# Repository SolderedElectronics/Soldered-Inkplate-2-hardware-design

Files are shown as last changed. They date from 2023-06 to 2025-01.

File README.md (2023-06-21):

# Inkplate 2 Hardware design

## About the product

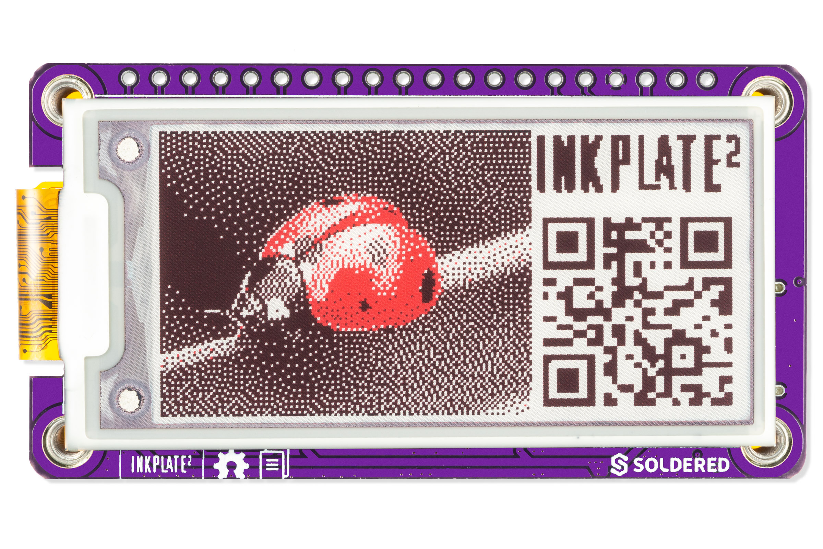
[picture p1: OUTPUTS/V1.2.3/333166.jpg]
Inkplate 2
|  |
| :----------------------------------------------------------: |
|      [Buy Inkplate 2](https://www.solde.red/333166)      |

The Inkplate 2 is an Arduino-compatible board that features a 2.13" three-color e-paper display. It is a plug-and-play device, programmable via USB port, and controlled by an ESP32 microcontroller. Moreover, it connects to the internet via WiFi or Bluetooth. Since it uses only 8uA in low-power mode, it can last for months on a single Li-ion battery charge. It's simple enough to be used by beginners, but it also offers plenty of features and a user-friendly platform for advanced users. Inkplate 2 has it all, packed on a small-factor board.

If you're like us, when you first saw an e-book reader, you thought "If only I could use a screen like this in my project". Thanks to the exceptional sharpness and contrast, the ability to display in sunlight and truly unprecedented efficiency in terms of energy (it consumes energy only when changing the content on the screen), electronic paper is the ideal choice for many applications. Inkplate 2, continuing the tradition of the now well-known Inkplate series, offers a variation of e-paper accessible to hobbyists and everyone else in a way that we have created a plug-and-play hardware that is really easy to use, and is compatible with Arduino and micropython.

## Repository contents

All Soldered Electronics hardware designed in KiCAD, and repositories are organized in the following way:

- CAD folder - contains KiCAD files (Schematics, Board, Panel Board), sorted by version. Change log lists all changes between versions.
- OUTPUTS - contains useful files, such as Bill of Materials (BOM), PDF of schematics, 3D .step file of the board and gerber files, sorted by version. 
- OUTPUTS -> Compliance - Certificates and useful legal stuff. 

## Want to contribute?

Please feel free to submit a pull request if you have any contributions. We encourage you to submit an issue or pull request if you find a bug. 

## About Soldered

soldered-logo

At Soldered, we design and manufacture a wide selection of electronic products to help you turn your ideas into acts and bring you one step closer to your final project. Our products are intented for makers and crafted in-house by our experienced team in Osijek, Croatia. We believe that sharing is a crucial element for improvement and innovation, and we work hard to stay connected with all our makers regardless of their skill or experience level. Therefore, all our products are open-source. Finally, we always have your back. If you face any problem concerning either your shopping experience or your electronics project, our team will help you deal with it, offering efficient customer service and cost-free technical support anytime. Some of those might be useful for you:

- [Web Store](https://www.soldered.com/shop)
- [Tutorials & Projects](https://soldered.com/learn)
- [Community & Technical support](https://soldered.com/community)

## License info

All Soldered open-source hardware (OSH) is under The TAPR Open Hardware License. Read more in the LICENSE file. 

No warranty - all designs in this repository are distributed in the hope that they will be useful, but without any warranty. They are provided "AS IS", therefore without warranty of any kind, either expressed or implied. The entire quality and performance of what you do with the contents of this repository are your responsibility. In no event, Soldered Electronics will be liable for your damages, losses, including any general, special, incidental or consequential damage arising out of the use or inability to use the contents of this repository. 

## Have fun! 
And thank you from your fellow makers at Soldered Electronics.

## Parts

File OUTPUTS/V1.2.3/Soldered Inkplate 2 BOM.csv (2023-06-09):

Id | Designator | Package | Quantity | Designation | Supplier and ref
1 | K15,K13,K16,K22,K4,K12,K9,K3,K8,K14,K21,K18,K10,K25,K6,K17,K1,K7,K5,K11 | HEADER_MALE_1X1_Inkplate | 20 | HEADER_MALE_1X1_Inkplate
2 | D1 | 0402LED | 1 | RED
3 | PAD3,PAD5,PAD2,PAD1,PAD4 | PAD_2x1.5 | 5 | PAD_2x1.5
4 | Q2,Q3 | SOT-23-3 | 2 | NPN
5 | H3,H4,H2,H1 | Standoff_M3 | 4 | Standoff_M3
6 | C10,C6,C26,C5,C3,C12 | 0603C | 6 | 100n
7 | R2,R12,R1,R13 | 0603R | 4 | 10k
8 | U3 | SOT-23-5 | 1 | MCP73831T-2ATI/OT
9 | R15,R3,R16,R17,R18,R19,R14,R11 | 0603R | 8 | 100k
10 | R8,R9 | 0603R | 2 | 1k
11 | C4,C9,C7,C2,C13 | 0603C | 5 | 2u2
12 | C22,C23 | 1206C | 2 | CL31B475KBHNFNE
13 | D5,D4,D6 | SOD−123 | 3 | MBR0530T1G
14 | R4 | 0603R | 1 | 47R
15 | C11,C1,C8 | 1206C | 3 | 10u
16 | Q1 | SOT-23-3 | 1 | SSM3J358R,LF
17 | K20 | U262-161N-4BVC11 | 1 | U262-161N-4BVC11
18 | R22 | 0603R | 1 | 0603WAF470LT5E
19 | D2 | SOD-323 | 1 | BAT20J
20 | C19,C15,C18,C24,C14,C20,C21,C17,C16 | 0603C | 9 | C1608X5R1H105K080AB
21 | L1 | Inductor_SMD_7x6.6 | 1 | PSPMAA0603-100M-ANF
22 | U4 | TPS7A2633DRVR | 1 | TPS7A2633DRVR
23 | F1 | 1206FUSE | 1 | 1206FUSE_500mA
24 | R5 | 0402R | 1 | 2k2
25 | K19 | TX2400-FPC-5015 | 1 | TX2400-FPC-5015
26 | R6,R7 | 0603R | 2 | 5k1
27 | U6 | SOT-23-5 | 1 | TPS3840PL27DBVR
28 | K24 | SFV24R-2STBE1HLF | 1 | SFV24R-1STBE1HLF
29 | U1 | ESP32-WROVER | 1 | ESP32-WROVER-IE-N4R8
30 | SW1 | YTSA007A0151803B | 1 | YTSA007A0151803B
31 | R10 | 0603R | 1 | 2k49
32 | U2 | SOP-16 | 1 | CH340C
33 | Q7 | SOT-23-3 | 1 | CJ2310
34 | K2 | easyC-connector | 1 | easyC-SMD
35 | R21 | 0603R | 1 | 1M
36 | U5 | GDEH0213Z19 | 1 | GDEH0213Z19

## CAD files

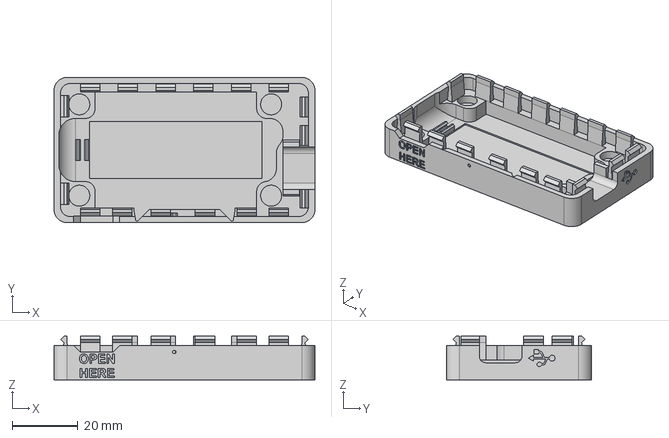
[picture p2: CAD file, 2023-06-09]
CAD/V1.2.3/Source 3D files/Soldered Inkplate 2 Bottom STEP.step
79.5 x 44.2 x 13.3 mm

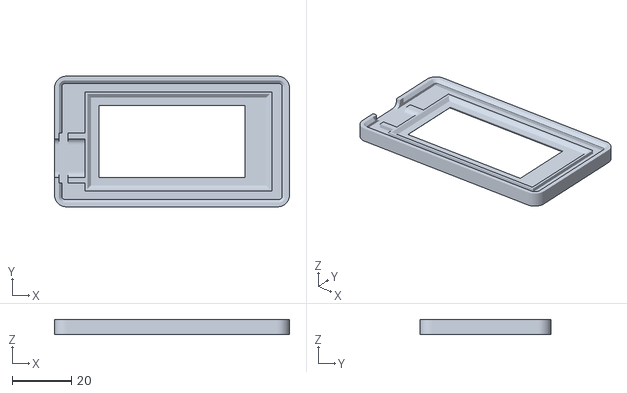
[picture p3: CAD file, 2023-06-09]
OUTPUTS/V1.2.3/3D printable files/Soldered Inkplate 2 Top STL.stl
79.5 x 44.2 x 5.00

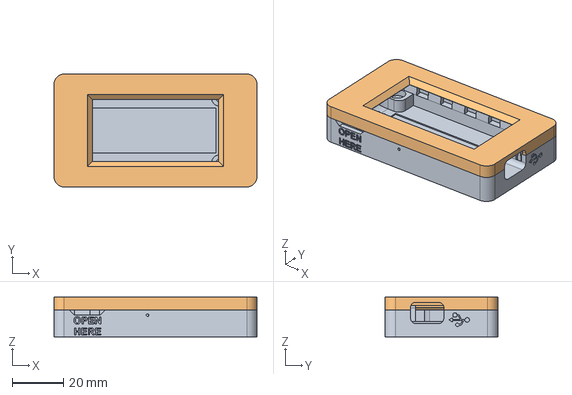
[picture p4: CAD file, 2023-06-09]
CAD/V1.2.3/Source 3D files/Soldered Inkplate 2 Case STEP.step
79.5 x 44.2 x 15.5 mm
Inkplate 2 Bottom
Inkplate 2 Top

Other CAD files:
OUTPUTS/V1.2.3/3D printable files/Soldered Inkplate 2 Case STL.stl
CAD/V1.2.3/Source 3D files/Soldered Inkplate 2 Top STEP.step
OUTPUTS/V1.2.3/3D printable files/Soldered Inkplate 2 Bottom STL.stl
CAD/V1.2.3/Source 3D files/Soldered Inkplate 2 Bottom 3D.f3d
CAD/V1.2.3/Source 3D files/Soldered Inkplate 2 Case 3D.f3z
CAD/V1.2.3/Source 3D files/Soldered Inkplate 2 Top 3D.f3d

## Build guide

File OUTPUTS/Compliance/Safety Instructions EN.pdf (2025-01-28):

PLEASE RETAIN THIS INFORMATION FOR FUTURE REFERENCE.

BEFORE USING THIS PRODUCT, READ ALL INSTRUCTION IN THIS DOCUMENT.

Product name: Soldered Inkplate 2
Getting started: To get started, please visit www.soldered.com

## WARNINGS

- This product should not be covered and should be operated in well ventilated enviroment.
- The product should be placed on a stable, flat, non-conductive surface and should not be contacted by conductive items.
- Connection of other devices may affect compliance or result in damage to the unit, and invalidate the warranty.
- Where peripherals are connected that do not include the cable or connector, the cable or connector used must offer adequate insulation and operation in order that the requirements of the relevant performance and safety requirements are met.
- There is a danger of explosion if the battery is incorrectly placed.
- The product should not be used outside of its specified working range.

## INSTRUCTIONS FOR SAFE USE

To avoid malfunction or damage to your device, please observe the following:
- Do not expose it to water, moisture or place on a conductive surface when turned on. Do not handle the unit with wet hands.
- Do not expose it to heat from any source; the product is designed to be used at normal ambient room temperatures. The product is intended to be used inside.
- Take care when handling to avoid mechanical or electrical damage to any part of the unit. Avoid handling the unit while it's powered. Use ESD protection.
- Use only supplied cable (or the cable of the same or higher quality) with the unit.

## COMPLIANCE INFORMATION

The product complies with the relevant provision of the RoHS Directive for the European Union. In common with all Electrical and Electronic Equipment (EEE), the product should not be disposed household waste.

ELECTROMAGNETIC COMPABILITY AND OPERATION

- The product is in conformity with the protection requirements of EU Council Directive 2014/30/EU on the laws of the Member States relating of electromagnetic compability, and Electromagnetic Compability Regulations 2016 of the UK.
- WARNING: Please do not alter the design of this product, doing so may void your ability to use the product freely, this includes altering the frequency at which product operates.

### Regulatory Compliance and Important Safety Information

Soldered Electronics d.o.o., Vinkovačka cesta 68, 31000 Osijek, Croatia. VAT ID: HR83200237288

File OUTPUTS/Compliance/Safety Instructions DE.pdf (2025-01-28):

BITTE BEWAHREN SIE DIESE INFORMATIONEN ZUR SPÄTEREN VERWENDUNG AUF.
LESEN SIE VOR DER VERWENDUNG DIESES PRODUKTS ALLE ANWEISUNGEN IN DOKUMENT. Produktname: Soldered Inkplate 2
Die ersten Schritte:Besuchen Sie www.soldered.com, um loszulegen.

## WARNUNGEN

- Dieses Produkt sollte nicht abgedeckt werden und in einer gut belüfteten Umgebung betrieben werden.
- Das Produkt sollte auf einer stabilen, flachen, nicht leitenden Oberfläche aufgestellt werden und nicht mit leitenden Gegenständen in Berührung kommen.
- Der Anschluss anderer Geräte kann die Konformität beeinträchtigen oder zu Schäden am Gerät führen und zum Erlöschen der Garantie führen.
- Wenn Peripheriegeräte angeschlossen werden, die nicht das Kabel oder den Stecker enthalten, muss das verwendete Kabel oder muss das verwendete Kabel bzw. der verwendete Steckverbinder eine angemessene Isolierung und Funktion aufweisen, damit die Anforderungen die einschlägigen Leistungs- und Sicherheitsanforderungen erfüllt werden.
- Es besteht Explosionsgefahr, wenn die Batterie falsch eingesetzt wird.
- Das Produkt sollte nicht außerhalb des angegebenen Arbeitsbereichs verwendet werden.

## HINWEISE ZUR SICHEREN ANWENDUNG

Um Fehlfunktionen oder Schäden an Ihrem Gerät zu vermeiden, beachten Sie bitte die folgenden Hinweise:
- Setzen Sie das Gerät nicht Wasser oder Feuchtigkeit aus und stellen Sie es nicht auf eine
leitende Oberfläche, wenn es eingeschaltet ist. Das Gerät nicht mit nassen Händen anfassen.
- Setzen Sie es keiner Wärmequelle aus; das Produkt ist für die Verwendung bei normalen Raumtemperaturen ausgelegt. Das Produkt ist für die Verwendung in Innenräumen vorgesehen.
- Seien Sie bei der Handhabung vorsichtig, um mechanische oder elektrische Schäden an Teilen des Geräts zu vermeiden. Fassen Sie das Gerät nicht an, wenn es unter Spannung steht. Verwenden Sie einen ESD-Schutz.
- Verwenden Sie nur das mitgelieferte Kabel (oder ein gleich- oder höherwertiges Kabel)
mit dem Gerät.

## COMPLIANCE-INFORMATIONEN

Das Produkt entspricht den entsprechenden Bestimmungen der RoHS-Richtlinie für die Europäische Union. Wie alle elektrischen und elektronischen Geräte (EEE), sollte das Produkt nicht über den Hausmüll entsorgt werden.
ELEKTROMAGNETISCHE VERTRÄGLICHKEIT UND BETRIEB
- Das Produkt entspricht den Schutzanforderungen der Richtlinie des EU-Rates 2014/30/EU über die Rechtsvorschriften der Mitgliedstaaten zur elektromagnetischen Verträglichkeit und den Elektromagnetische Verträglichkeitsverordnung 2016 des Vereinigten Königreichs.
- WARNUNG: Bitte verändern Sie nicht das Design dieses Produkts, da dies dazu führen kann, dass Sie das Produkt nicht mehr uneingeschränkt nutzen können.
Dies gilt auch für die Änderung der Frequenz, mit der das Produkt arbeitet.

## Einhaltung gesetzlicher Vorschriften und wichtige

Soldered Electronics d.o.o., Vinkovačka cesta 68, 31000 Osijek, Croatia. VAT ID: HR83200237288

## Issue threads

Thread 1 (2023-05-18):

Can we get a footprint library please

JanZugic, 2023-05-18:
i wish to create a custom case, but for that i need either a 3D model footprint library or a 3D model (preferably STEP) of the unit.

JanZugic, 2023-05-18:
Its in  the outputs folder...

rsoric, 2023-05-19:
Hi @JanZugic

Glad you could find it, let us know if you might need something else for your case design.

-Rob

JanZugic, 2023-05-19:
Hello! Are you located in Zagreb?

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

rsoric, 2023-05-22:
Hi @JanZugic

We are located in Osijek. If you want to get further in touch with us, we recommend the contact form on our website: https://soldered.com/contact/

Closed 2023-05-18.

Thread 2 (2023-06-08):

Can we get the case files in STL format

Jakobu5, 2023-06-08:
Hi,

awesome products you have there guys.

Could you please provide the case files for all of your inkplates also in the STL format?
Thank you!

davidzovko, 2023-06-08:
Hey,

thanks! Of course, we are retrofitting repositories for older Inkplates with the format of this repo, and it will be ready by the end of the next week.

If you need any specific one before, let us know here, and we'll deliver.

Cheers!

Jakobu5, 2023-06-08:
Thanks for the swift reply,
I need the files for the inkplate 2 and inkplate 6 plus
Thanks!

ifadiga, 2023-06-09:
Hello,
[3D printable files_Inkplate2.zip](https://github.com/SolderedElectronics/Soldered-Inkplate-2-hardware-design/files/11702460/3D.printable.files_Inkplate2.zip)
[3D printable files_Inkplate6PLUS.zip](https://github.com/SolderedElectronics/Soldered-Inkplate-2-hardware-design/files/11702461/3D.printable.files_Inkplate6PLUS.zip)

Here are the files for Inkplate 2 and Inkplate 6PLUS.

Closed 2023-06-09.

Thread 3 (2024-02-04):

Neispravna poveznica na sliku u README.md ?

sbravar, 2024-02-04:
https://github.com/SolderedElectronics/Soldered-Inkplate-2-hardware-design/blob/d8ae98a4285a7189eac2a7881446ffaee9f6e620/README.md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

umjesto:

https://github.com/SolderedElectronics/Inkplate-2-hardware-design/blob/main/OUTPUTS/V1.1.1/333166.jpg?raw=true

čini mi se da bi trebalo biti:

https://github.com/SolderedElectronics/Soldered-Inkplate-2-hardware-design/blob/main/OUTPUTS/V1.2.3/333166.jpg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

rsoric, 2024-02-05:
Hello, and thank you for your feedback. We are currently working on automating this process. Soon, all repositories will be updated with the real content. Cheers!

Closed 2024-02-05.

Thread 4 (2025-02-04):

Broken link to https://soldered.com/learn in  inkplate2 README.md

bivanbi, 2025-02-04:
https://github.com/SolderedElectronics/Soldered-Inkplate-2-hardware-design/blob/main/README.md has a link called 'Tutorials & Projects' which points to a non-existing page https://soldered.com/learn
```
bivanbi@eenovo:~$ curl -iksS https://soldered.com/learn 2>&1 | head
HTTP/2 404
```

rsoric, 2025-02-18:
Greetings @bivanbi ,

thanks for pointing it out, this was a leftover link of something not fully implemented yet, but we are working on improving documentation for all our products.

-Rob

Closed 2025-02-18.

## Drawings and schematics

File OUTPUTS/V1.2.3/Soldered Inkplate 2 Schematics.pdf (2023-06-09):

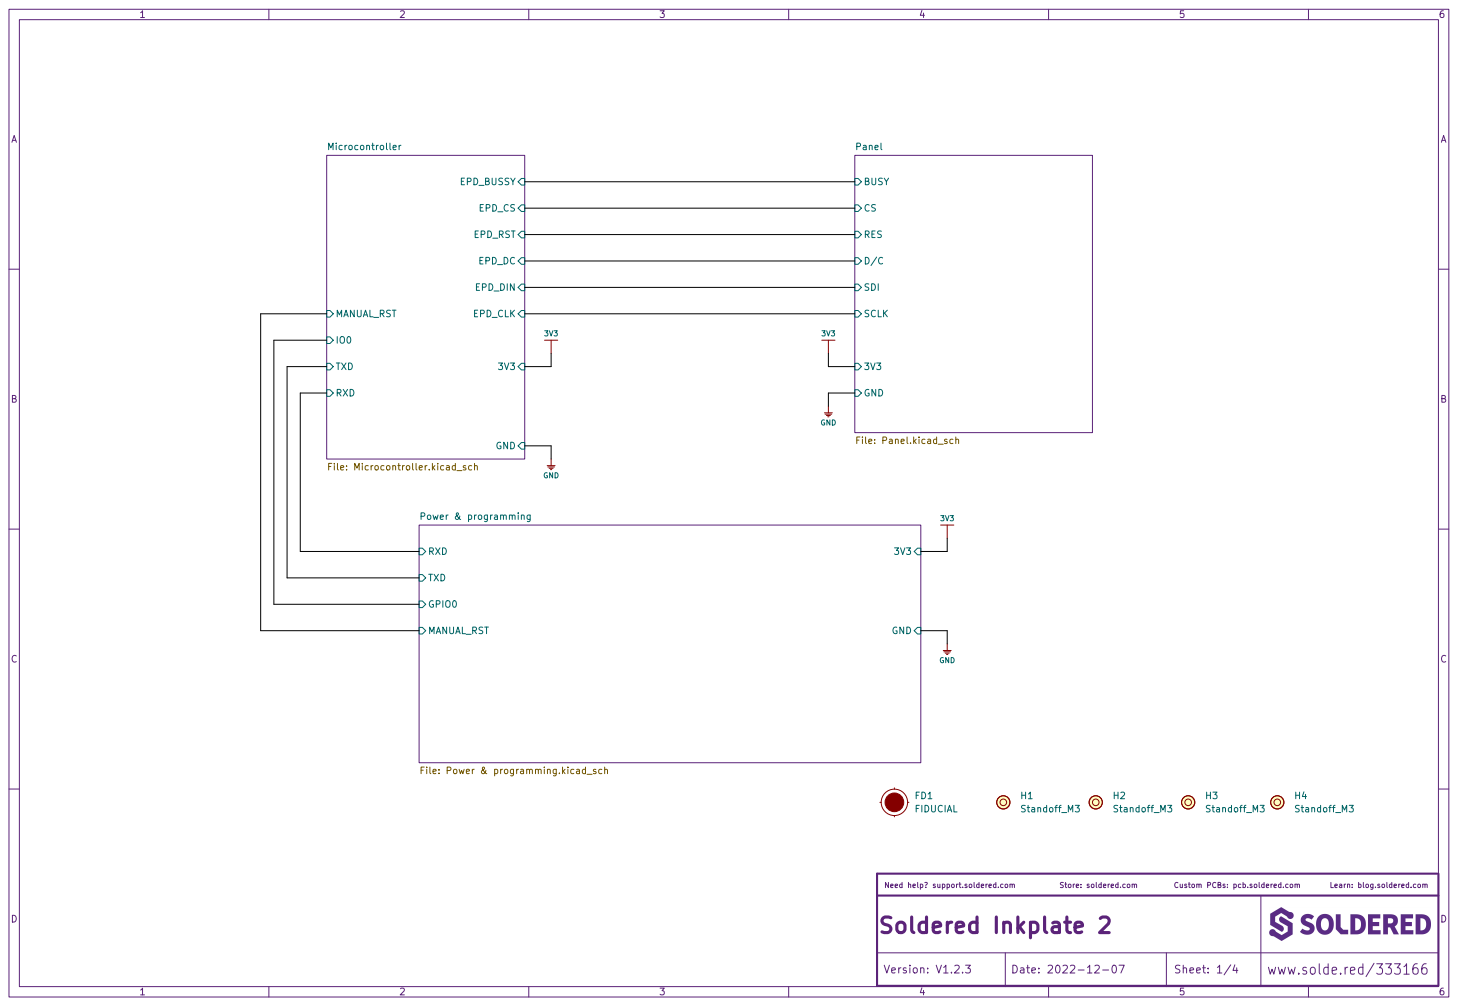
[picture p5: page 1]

Panel File: Panel.kicad_sch RXD

Learn: blog.soldered.com

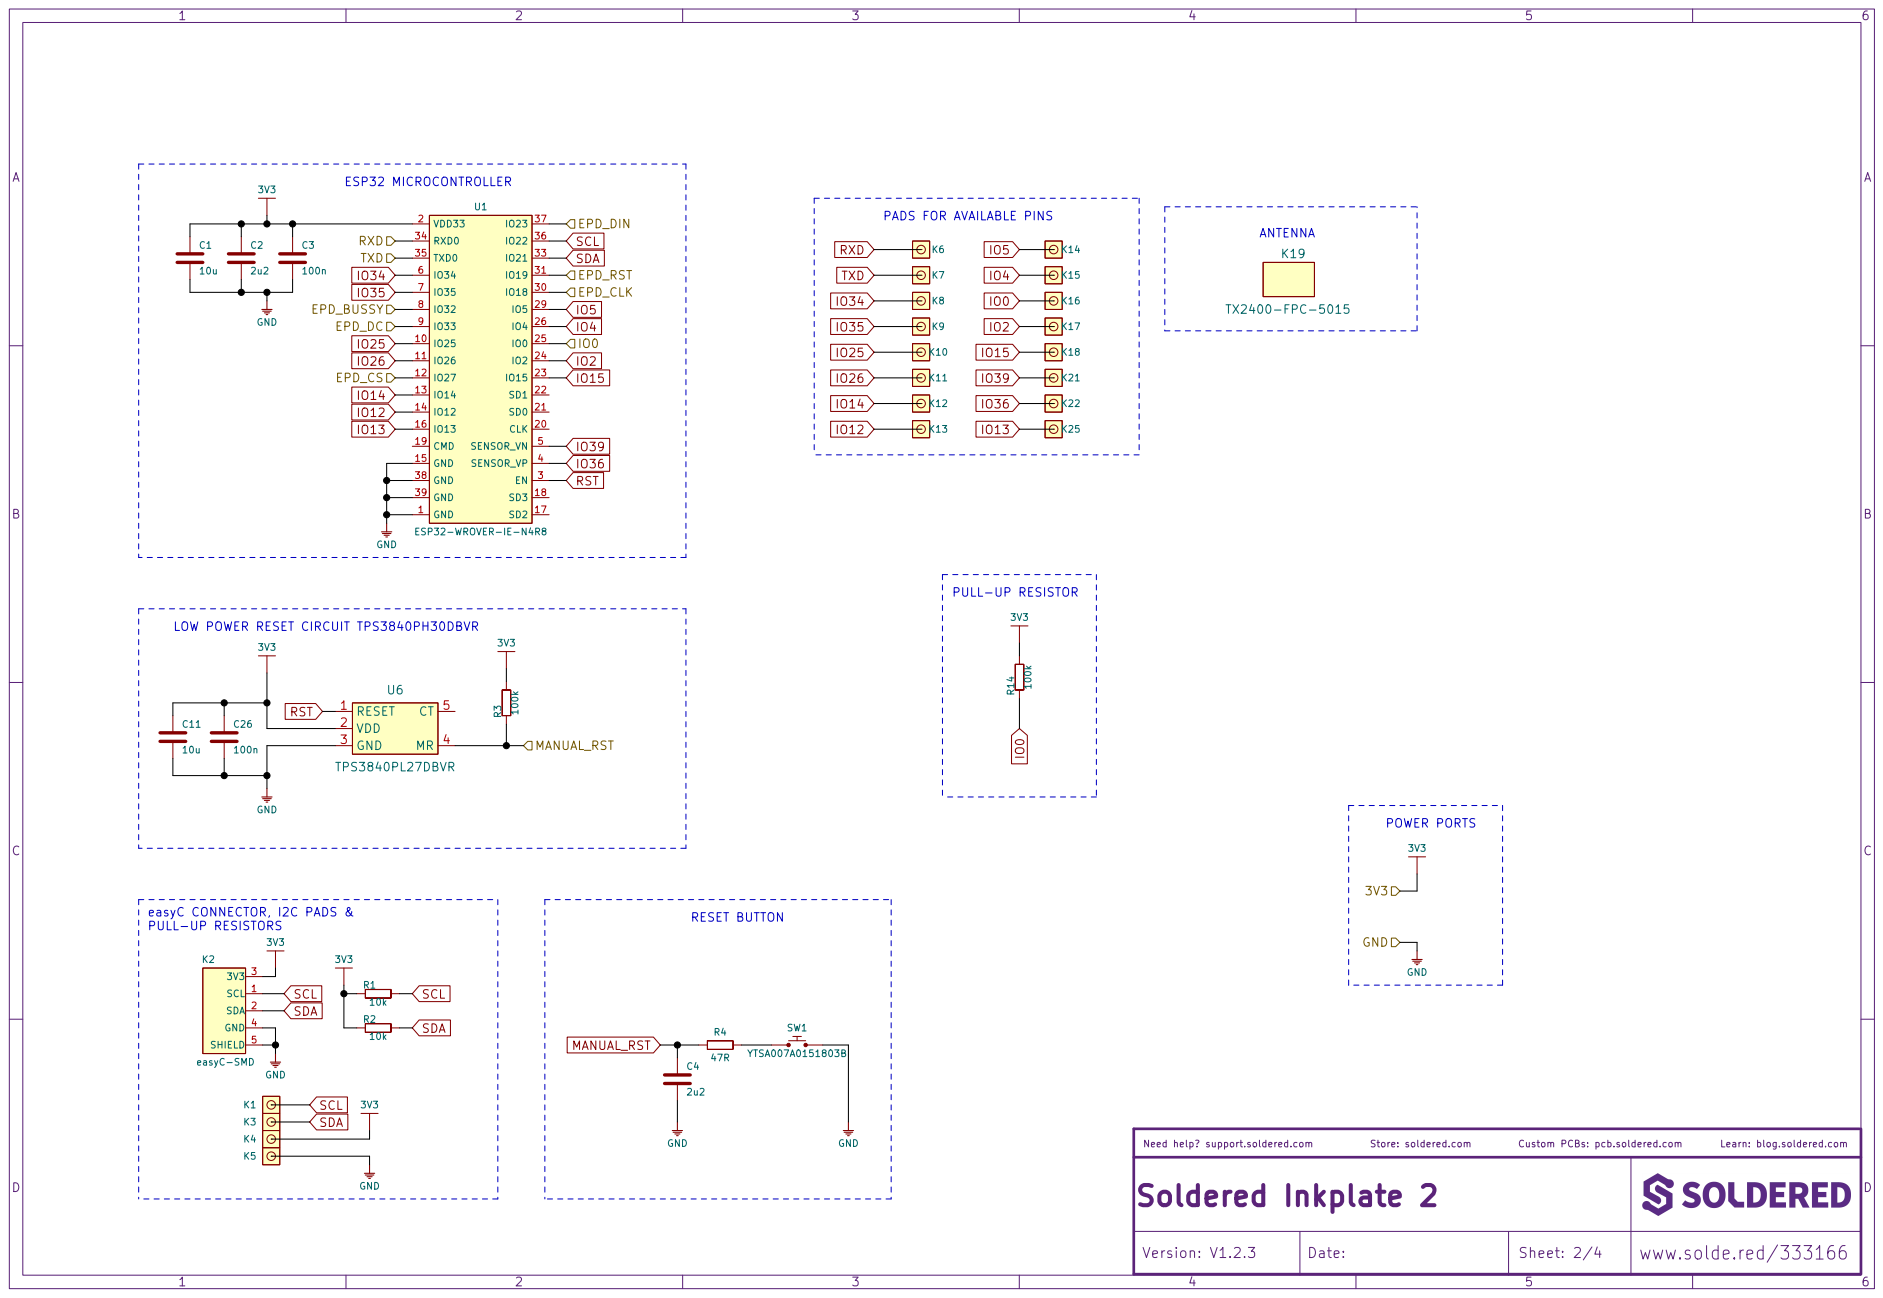
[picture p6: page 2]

LOW POWER RESET CIRCUIT TPS3840PH30DBVR

Learn: blog.soldered.com

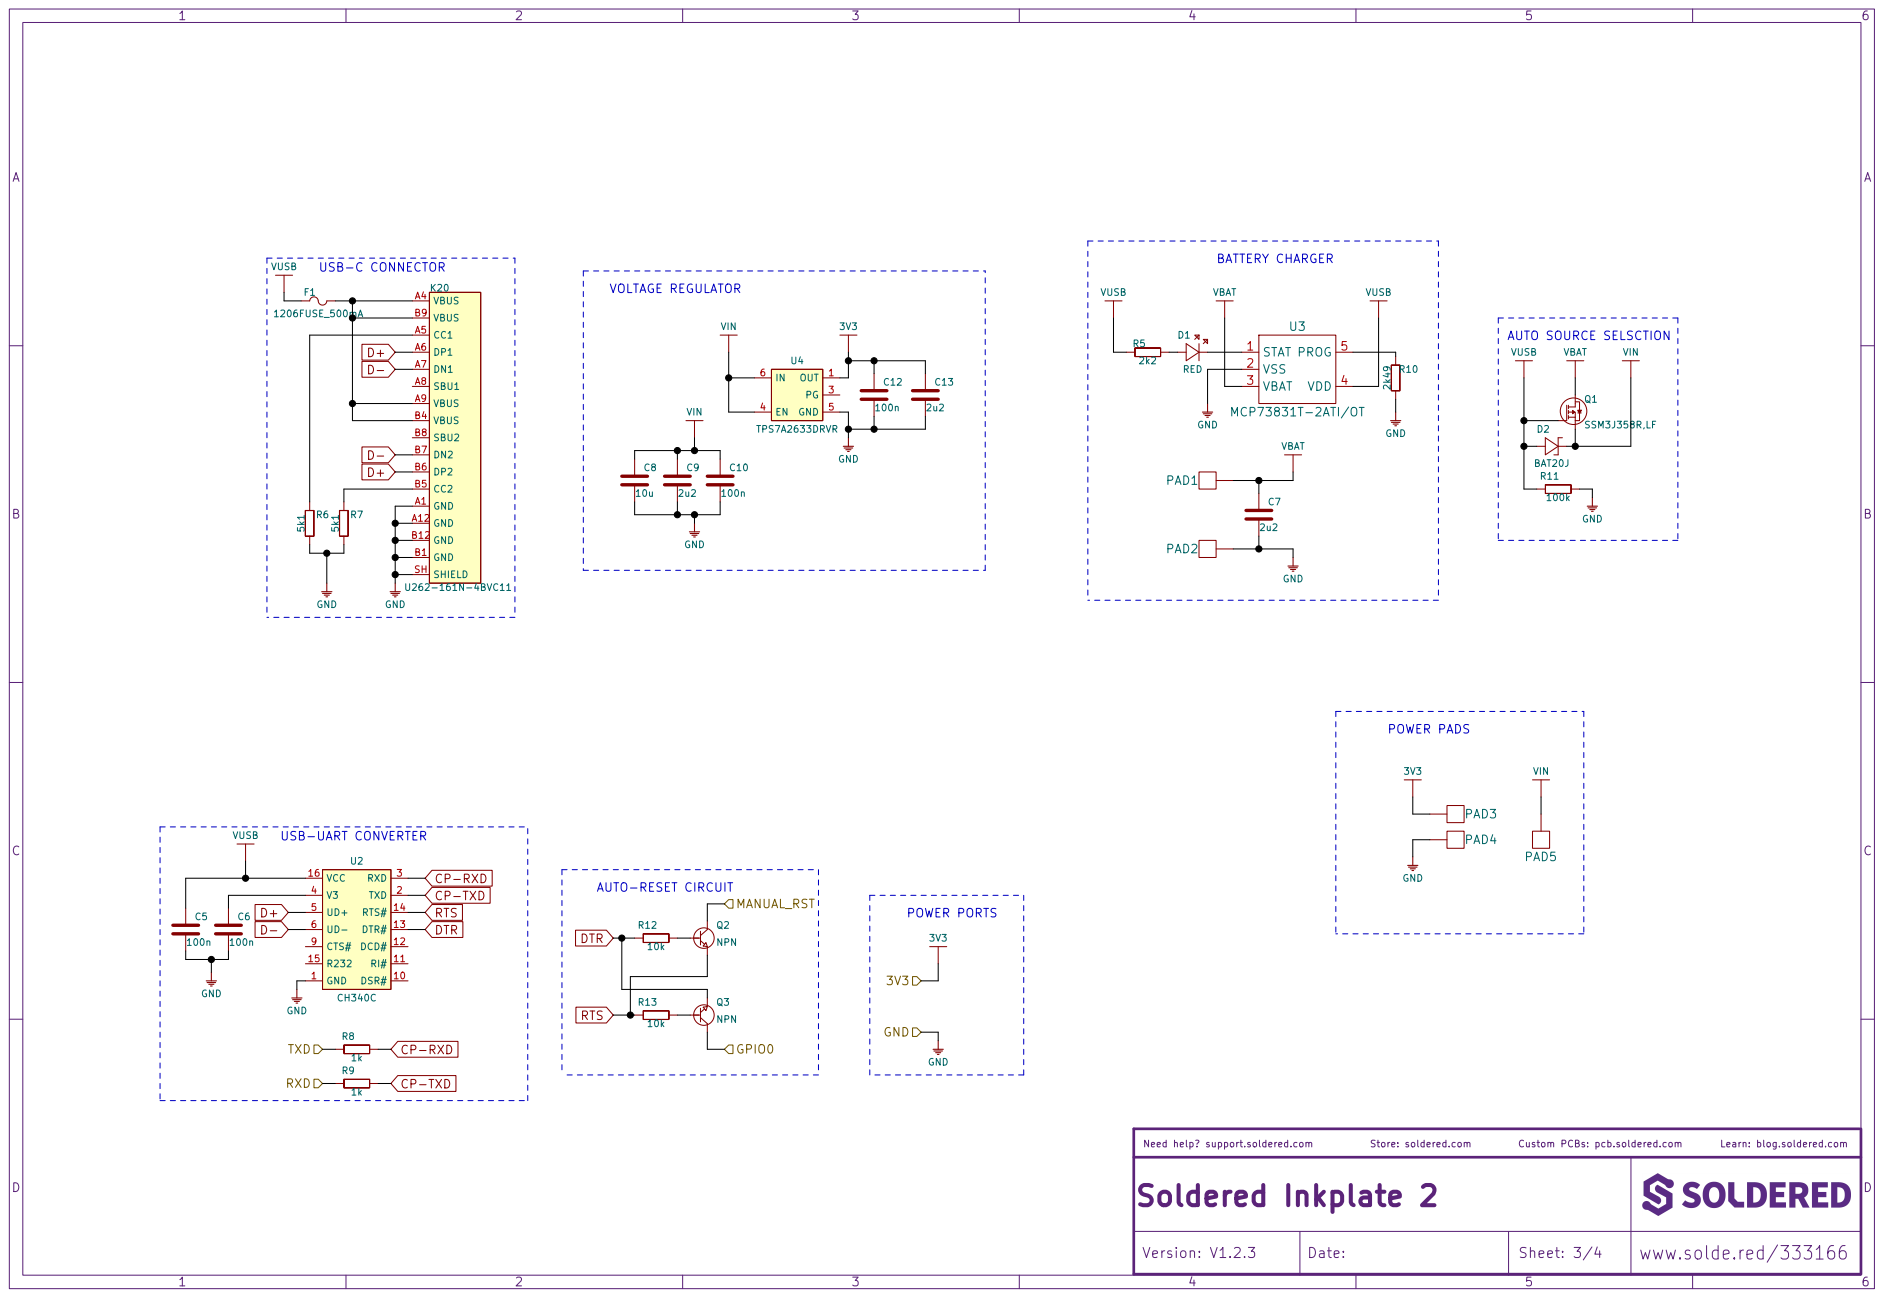
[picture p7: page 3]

Learn: blog.soldered.com

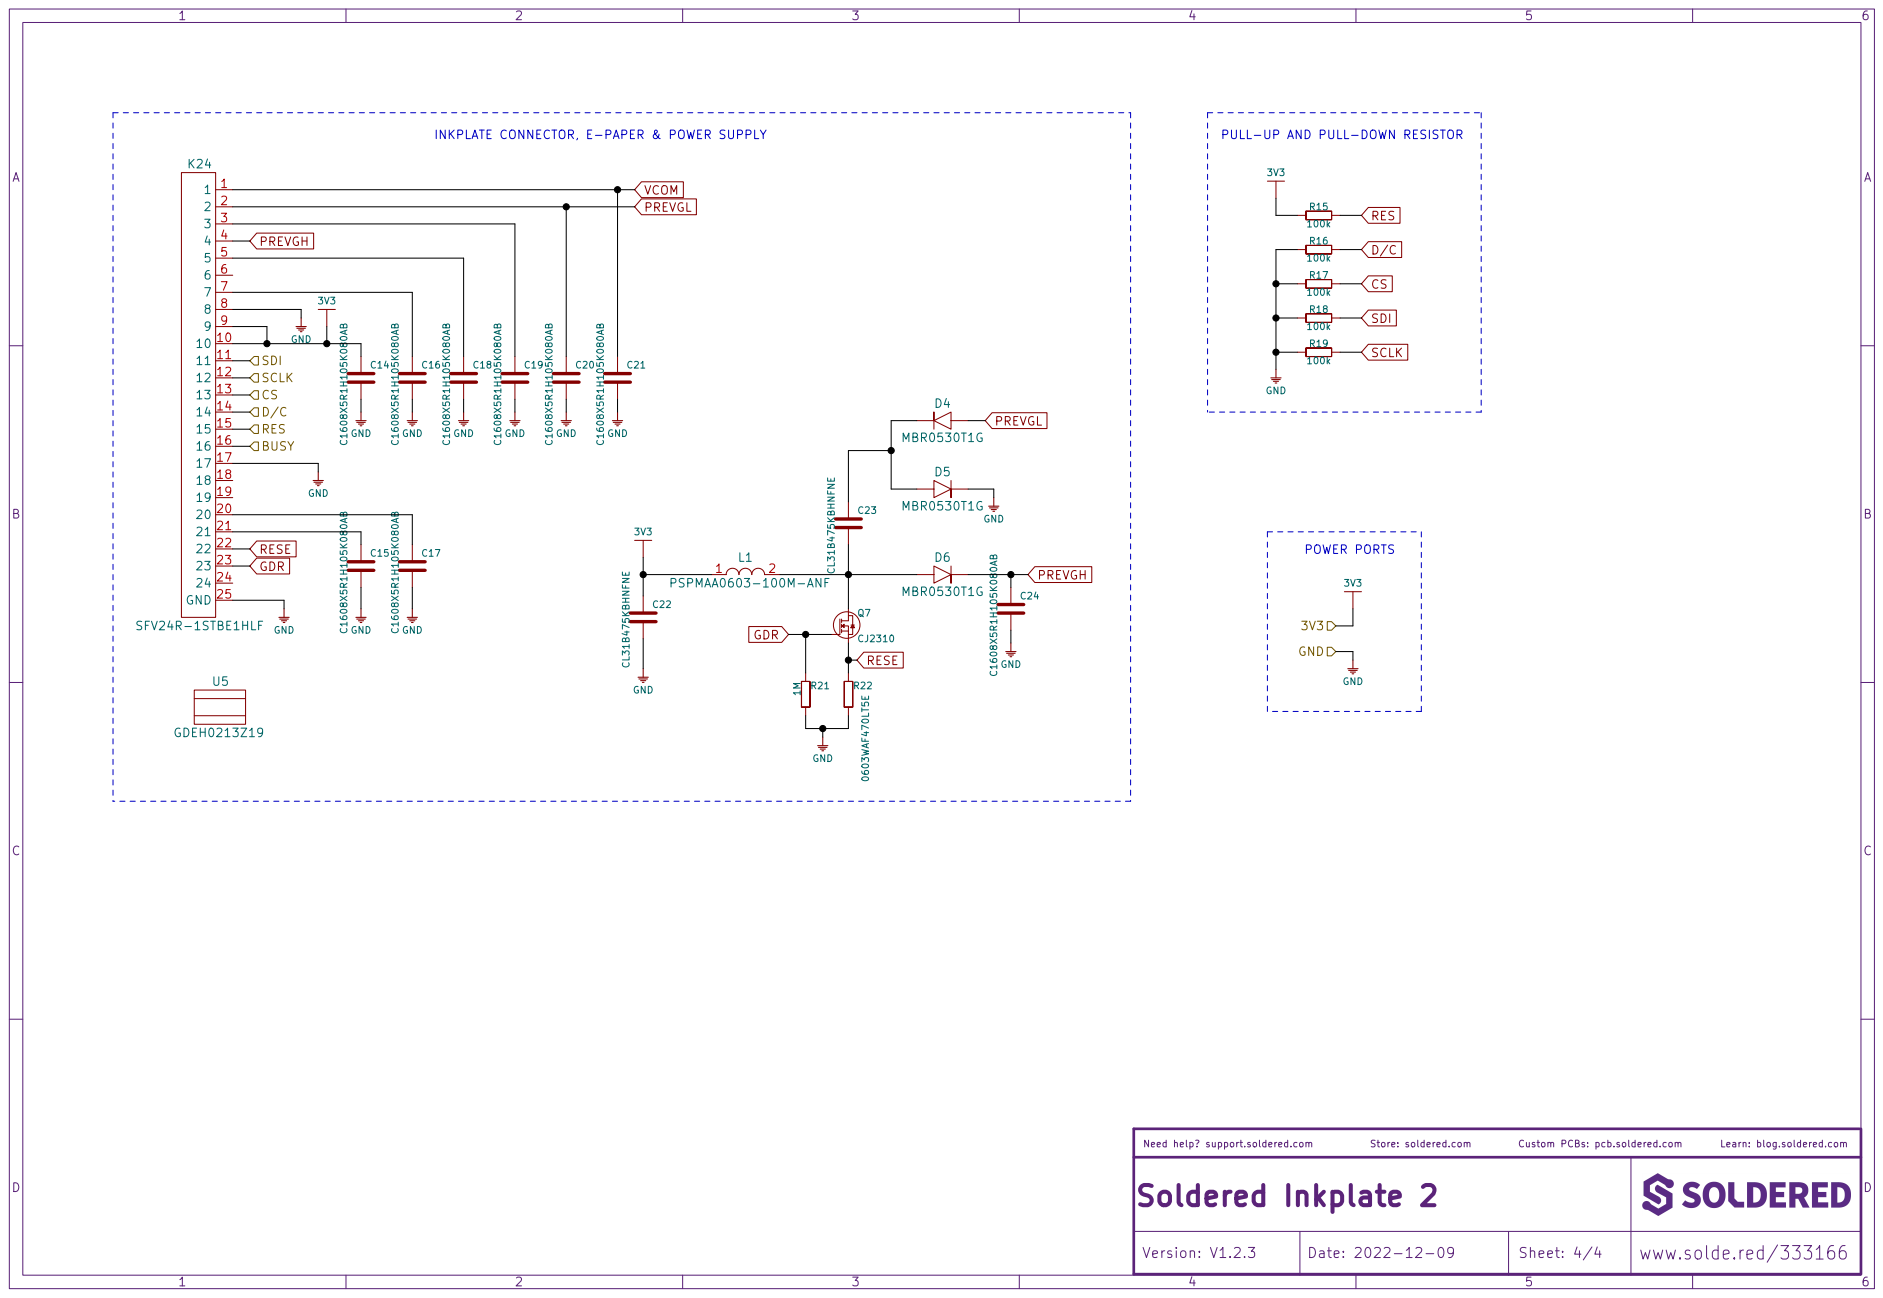
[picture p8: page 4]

INKPLATE CONNECTOR, E-PAPER & POWER SUPPLY
9 K24 SFV24R-1STBE1HLF
C17 C1608X5R1H105K080AB C15 C1608X5R1H105K080AB GND GND
SCLK RESE GDR

PULL-UP AND PULL-DOWN RESISTOR
100k GND

Learn: blog.soldered.com

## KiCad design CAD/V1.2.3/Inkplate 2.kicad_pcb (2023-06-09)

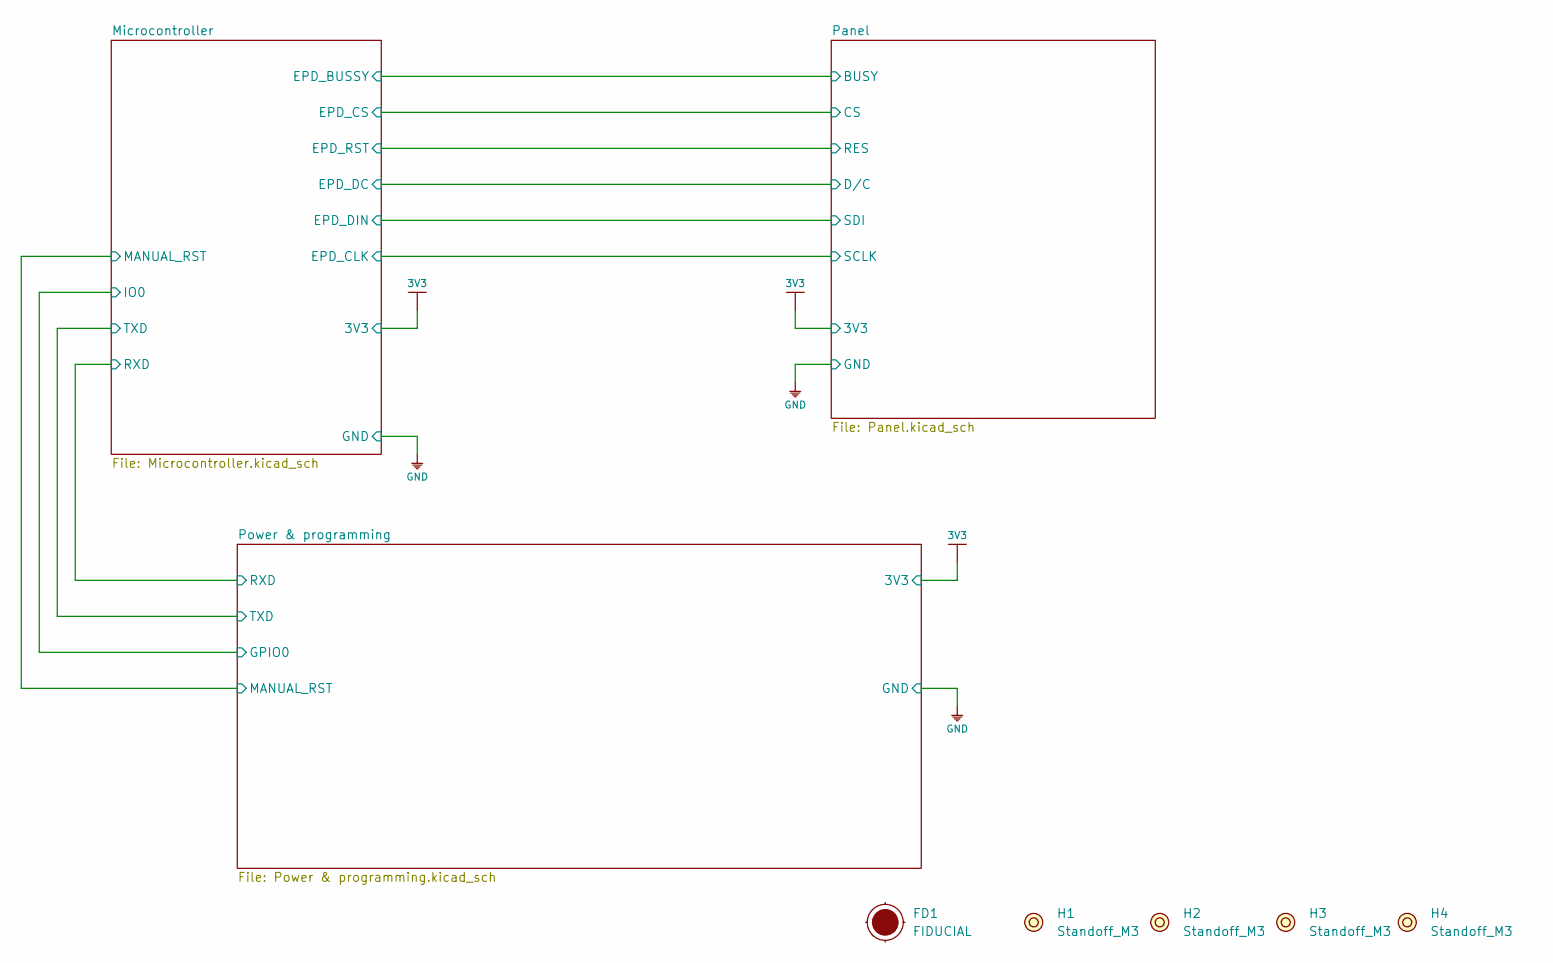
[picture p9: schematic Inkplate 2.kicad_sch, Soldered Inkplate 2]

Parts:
FD1: FIDUCIAL; FIDUCIAL_23
H1, H2, H3, H4: Standoff_M3

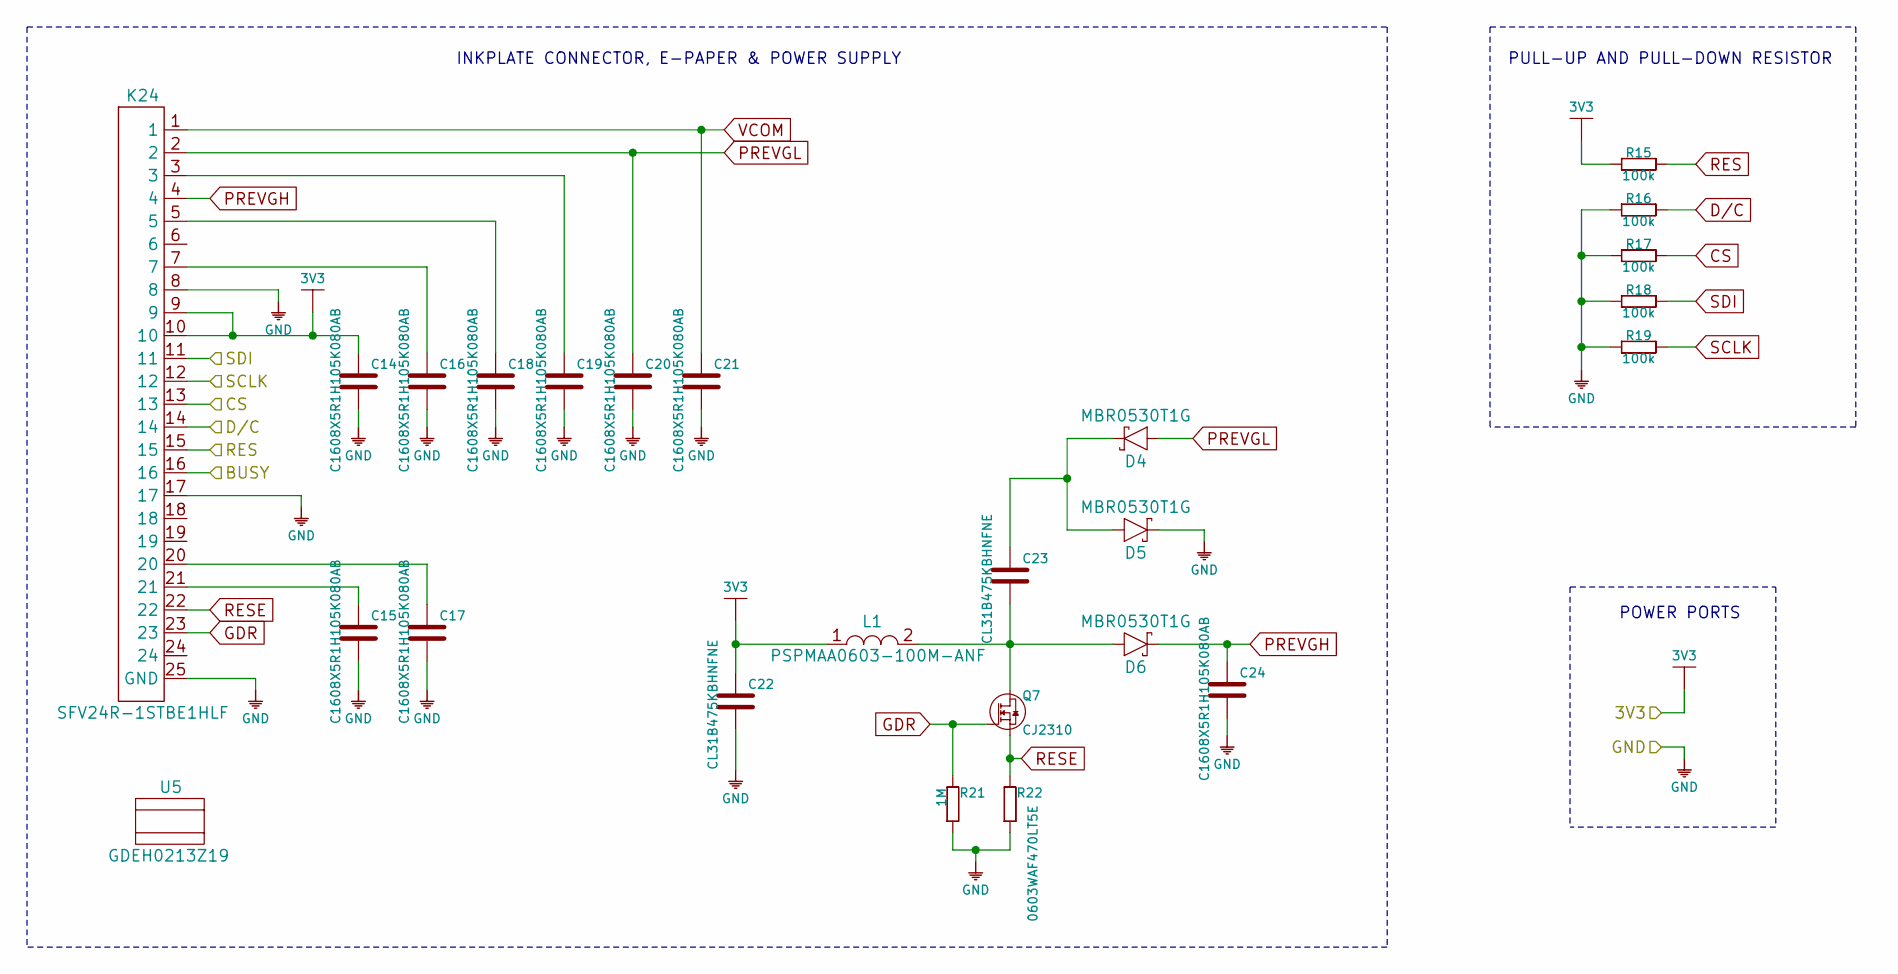
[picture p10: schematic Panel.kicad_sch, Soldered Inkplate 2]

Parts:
C14, C15, C16, C17, C18, C19, C20, C21, C24: C1608X5R1H105K080AB; 0603C
C22, C23: CL31B475KBHNFNE; 1206C
D4, D5, D6: MBR0530T1G; SOD-123
K24: SFV24R-1STBE1HLF; SFV24R-2STBE1HLF
L1: PSPMAA0603-100M-ANF; Inductor_SMD_7x6.6
Q7: CJ2310; SOT-23-3
R15, R16, R17, R18, R19: 100k; 0603R
R21: 1M; 0603R
R22: 0603WAF470LT5E; 0603R
U5: GDEH0213Z19

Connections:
3V3: C14.2, C22.2, K24.9, K24.10, L1.1, R15.1; also elsewhere on the board
/Microcontroller/EPD_BUSSY: K24.16; also elsewhere on the board
CS: K24.13, R17.2; also elsewhere on the board
D/C: K24.14, R16.2; also elsewhere on the board
GDR: K24.23, Q7.1 (G), R21.2
GND: C14.1, C15.1, C16.1, C17.1, C18.1, C19.1, C20.1, C21.1, C22.1, C24.1, D5.1 (C), K24.8, K24.17, K24.25 (GND), R16.1, R17.1, R18.1, R19.1, R21.1, R22.1; also elsewhere on the board
unnamed: C15.2, K24.21
unnamed: C16.2, K24.7
unnamed: C17.2, K24.20
unnamed: C18.2, K24.5
unnamed: C19.2, K24.3
unnamed: C23.1, D6.2 (A), L1.2, Q7.3 (D)
unnamed: C23.2, D4.1 (C), D5.2 (A)
PREVGH: C24.2, D6.1 (C), K24.4
PREVGL: C20.2, D4.2 (A), K24.2
RES: K24.15, R15.2; also elsewhere on the board
RESE: K24.22, Q7.2 (S), R22.2
SCLK: K24.12, R19.2; also elsewhere on the board
SDI: K24.11, R18.2; also elsewhere on the board
VCOM: C21.2, K24.1

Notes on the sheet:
INKPLATE CONNECTOR, E-PAPER & POWER SUPPLY
POWER PORTS
PULL-UP AND PULL-DOWN RESISTOR

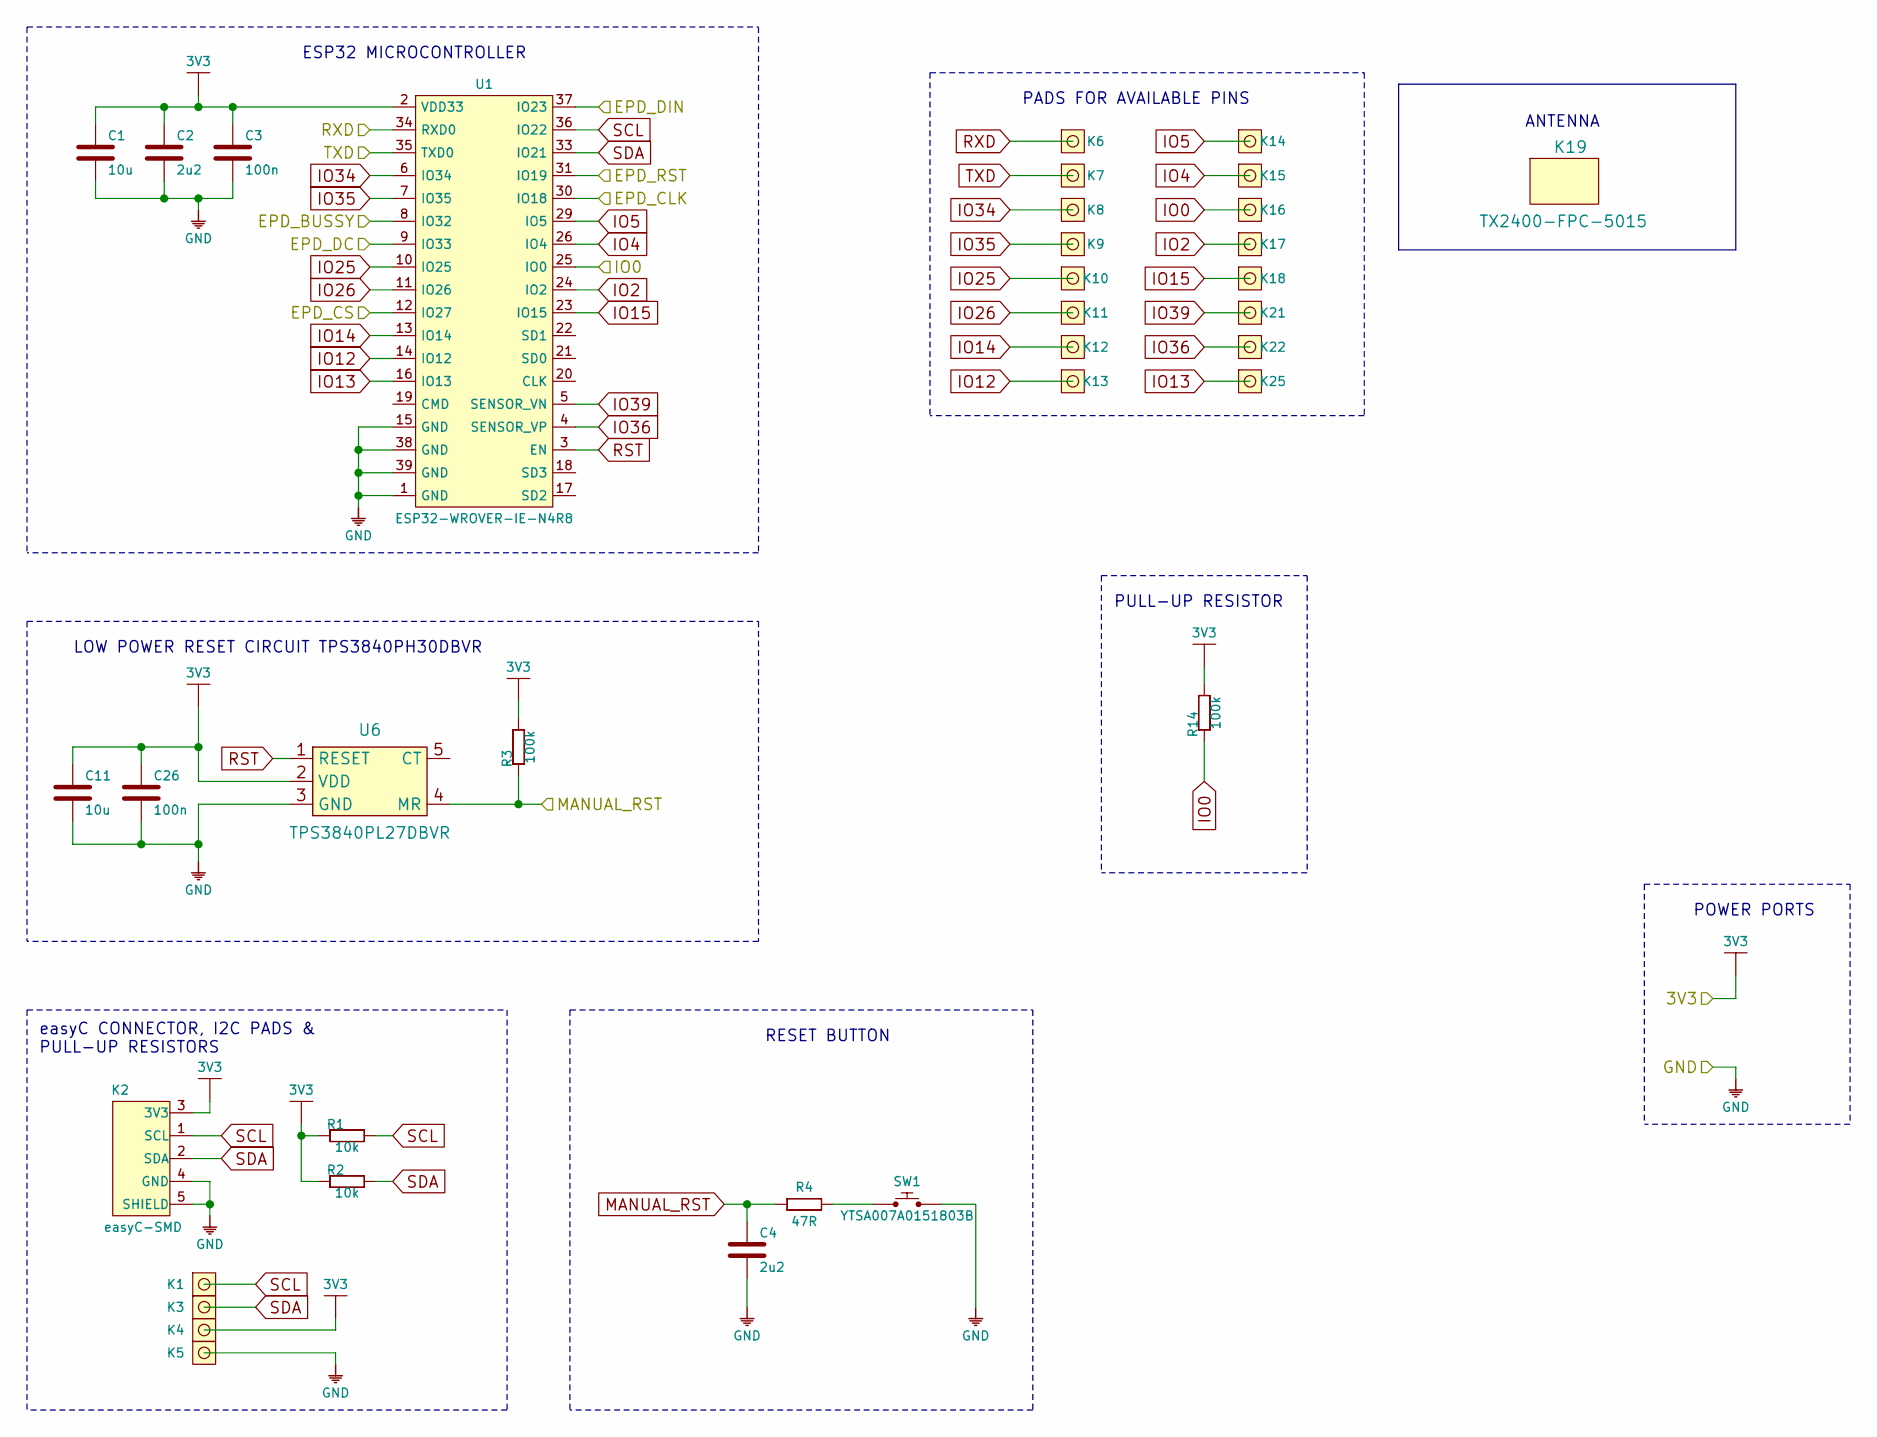
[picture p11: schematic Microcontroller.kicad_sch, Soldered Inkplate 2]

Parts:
C1, C11: 10u; 1206C
C2, C4: 2u2; 0603C
C3, C26: 100n; 0603C
K1, K3, K4, K5, K6, K7, K8, K9, K10, K11, K12, K13, K14, K15, K16, K17, K18, K21, K22, K25: HEADER_MALE_1X1_Inkplate
K2: easyC-SMD; easyC-connector
K19: TX2400-FPC-5015
R1, R2: 10k; 0603R
R3, R14: 100k; 0603R
R4: 47R; 0603R
SW1: YTSA007A0151803B
U1: ESP32-WROVER-IE-N4R8; ESP32-WROVER
U6: TPS3840PL27DBVR; SOT-23-5

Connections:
3V3: C1.2, C2.2, C3.2, C11.2, C26.2, K2.3 (3V3), K4.1, R1.1, R2.1, R3.2, R14.2, U1.2 (VDD33), U6.2 (VDD); also elsewhere on the board
/Microcontroller/EPD_BUSSY: U1.8 (IO32); also elsewhere on the board
CS: U1.12 (IO27); also elsewhere on the board
D/C: U1.9 (IO33); also elsewhere on the board
GND: C1.1, C2.1, C3.1, C4.1, C11.1, C26.1, K2.4 (GND), K2.5 (SHIELD), K5.1, SW1.2, U1.1 (GND), U1.15 (GND), U1.38 (GND), U1.39 (GND), U6.3 (GND); also elsewhere on the board
IO0: K16.1, R14.1, U1.25 (IO0); also elsewhere on the board
IO2: K17.1, U1.24 (IO2)
IO4: K15.1, U1.26 (IO4)
IO5: K14.1, U1.29 (IO5)
IO12: K13.1, U1.14 (IO12)
IO13: K25.1, U1.16 (IO13)
IO14: K12.1, U1.13 (IO14)
IO15: K18.1, U1.23 (IO15)
IO25: K10.1, U1.10 (IO25)
IO26: K11.1, U1.11 (IO26)
IO34: K8.1, U1.6 (IO34)
IO35: K9.1, U1.7 (IO35)
IO36: K22.1, U1.4 (SENSOR_VP)
IO39: K21.1, U1.5 (SENSOR_VN)
MANUAL_RST: C4.2, R3.1, R4.1, U6.4 (MR); also elsewhere on the board
unnamed: R4.2, SW1.1
RES: U1.31 (IO19); also elsewhere on the board
RST: U1.3 (EN), U6.1 (RESET)
RXD: K6.1, U1.34 (RXD0); also elsewhere on the board
SCL: K1.1, K2.1 (SCL), R1.2, U1.36 (IO22)
SCLK: U1.30 (IO18); also elsewhere on the board
SDA: K2.2 (SDA), K3.1, R2.2, U1.33 (IO21)
SDI: U1.37 (IO23); also elsewhere on the board
TXD: K7.1, U1.35 (TXD0); also elsewhere on the board

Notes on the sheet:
RESET BUTTON
POWER PORTS
LOW POWER RESET CIRCUIT TPS3840PH30DBVR
PULL-UP RESISTOR
ANTENNA
easyC CONNECTOR, I2C PADS & PULL-UP RESISTORS
PADS FOR AVAILABLE PINS
ESP32 MICROCONTROLLER

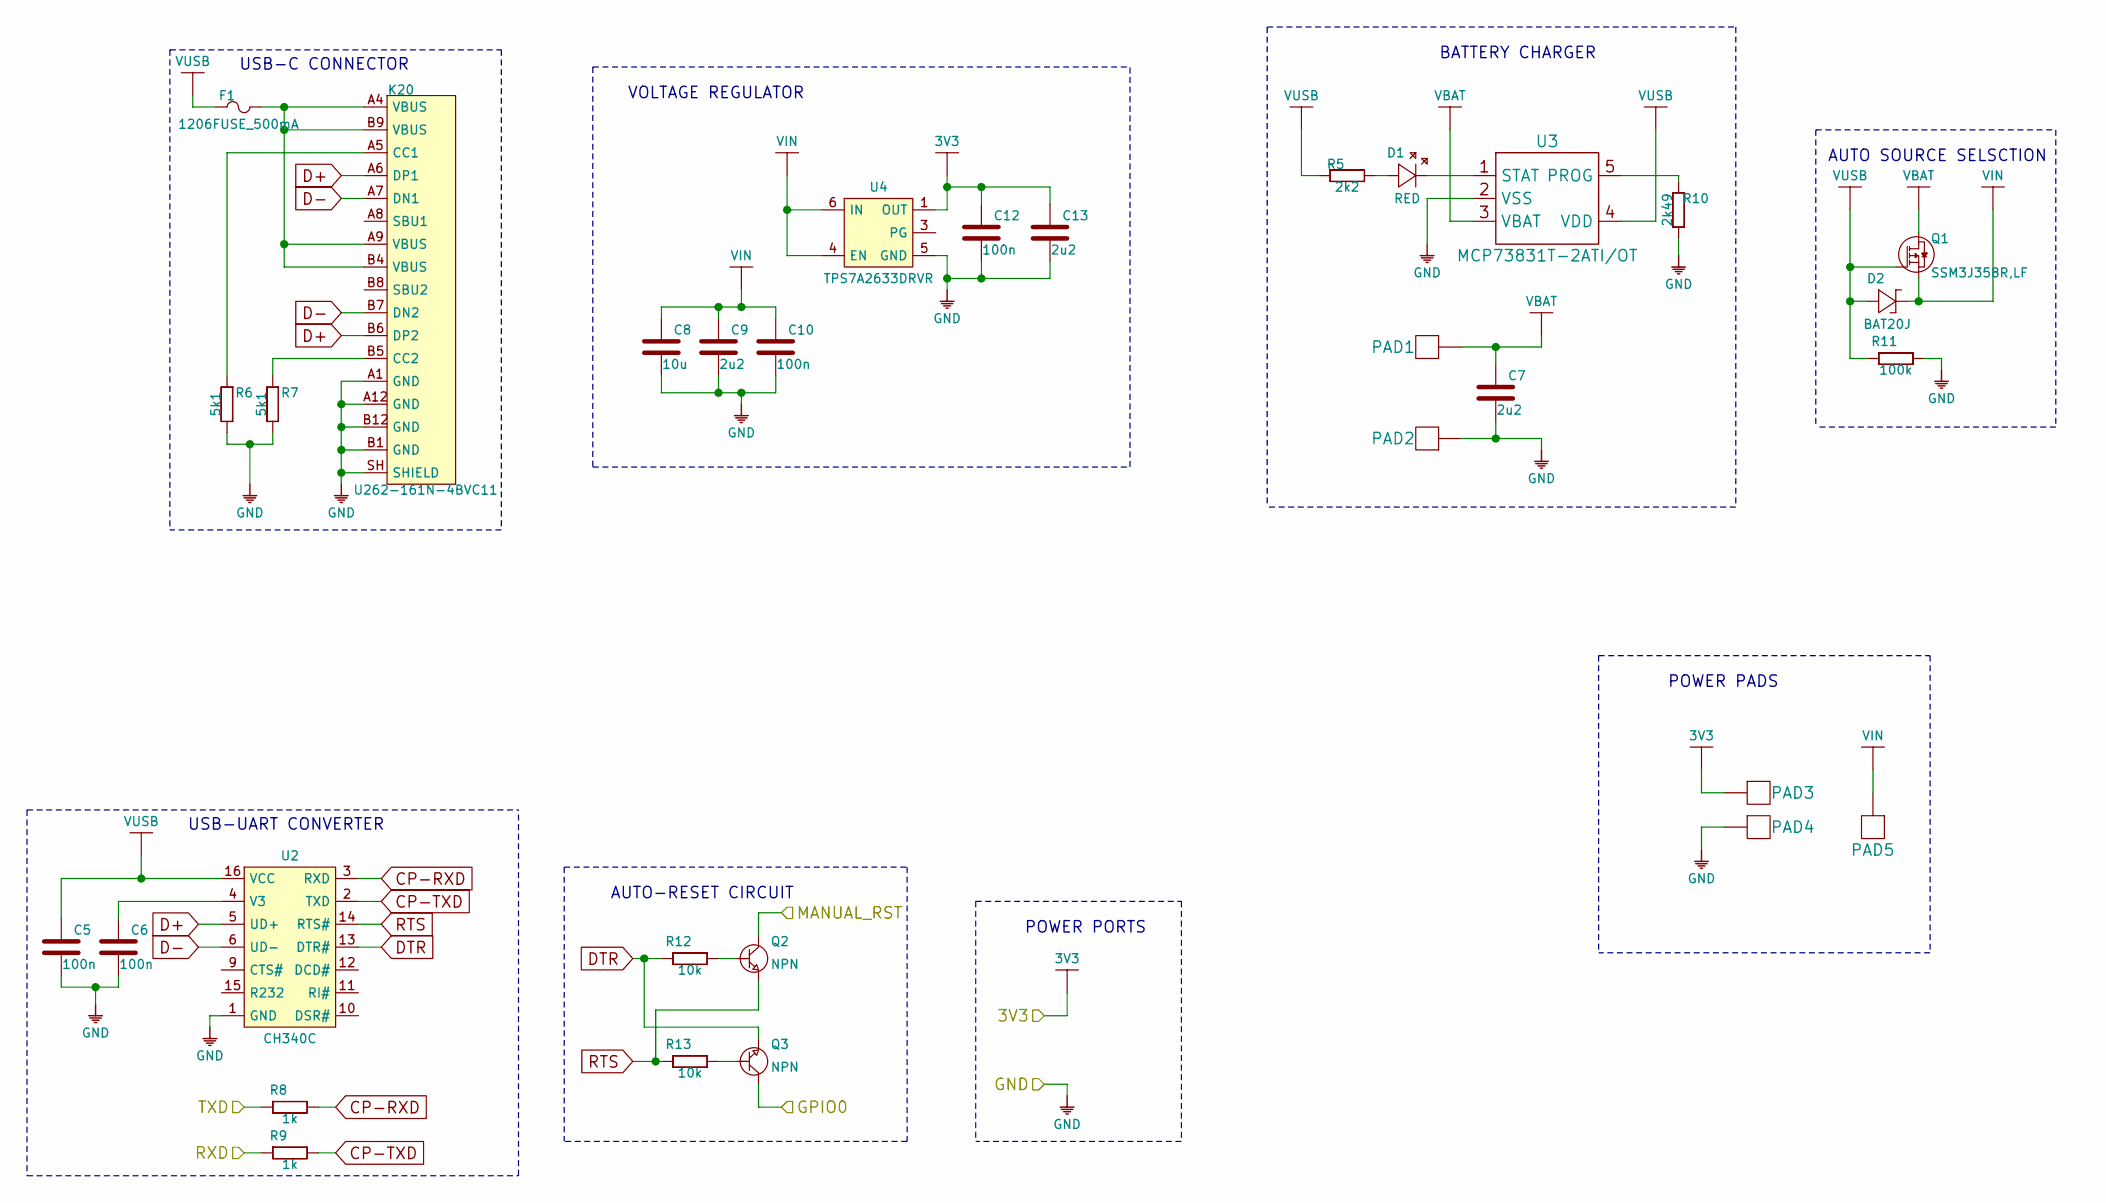
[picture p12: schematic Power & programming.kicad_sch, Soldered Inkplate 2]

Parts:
C5, C6, C10, C12: 100n; 0603C
C7, C9, C13: 2u2; 0603C
C8: 10u; 1206C
D1: RED; 0402LED
D2: BAT20J; SOD-323
F1: 1206FUSE_500mA; 1206FUSE
K20: U262-161N-4BVC11
PAD1, PAD2, PAD3, PAD4, PAD5: PAD_2x1.5
Q1: SSM3J358R,LF; SOT-23-3
Q2, Q3: NPN; SOT-23-3
R5: 2k2; 0402R
R6, R7: 5k1; 0603R
R8, R9: 1k; 0603R
R10: 2k49; 0603R
R11: 100k; 0603R
R12, R13: 10k; 0603R
U2: CH340C; SOP-16
U3: MCP73831T-2ATI/OT; SOT-23-5
U4: TPS7A2633DRVR

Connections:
3V3: C12.2, C13.2, PAD3.1, U4.1 (OUT); also elsewhere on the board
CP-RXD: R8.2, U2.3 (RXD)
CP-TXD: R9.2, U2.2 (TXD)
D+: K20.A6 (DP1), K20.B6 (DP2), U2.5 (UD+)
D-: K20.A7 (DN1), K20.B7 (DN2), U2.6 (UD-)
DTR: Q3.2 (E), R12.1, U2.13 (DTR#)
GND: C5.1, C6.1, C7.1, C8.1, C9.1, C10.1, C12.1, C13.1, K20.A1 (GND), K20.A12 (GND), K20.B1 (GND), K20.B12 (GND), K20.SH (SHIELD), PAD2.1, PAD4.1, R6.2, R7.2, R10.2, R11.2, U2.1 (GND), U3.2 (VSS), U4.5 (GND); also elsewhere on the board
IO0: Q3.3 (C); also elsewhere on the board
MANUAL_RST: Q2.3 (C); also elsewhere on the board
unnamed: C6.2, U2.4 (V3)
unnamed: D1.1 (A), R5.2
unnamed: D1.2 (K), U3.1 (STAT)
unnamed: F1.2, K20.A4 (VBUS), K20.A9 (VBUS), K20.B4 (VBUS), K20.B9 (VBUS)
unnamed: K20.A5 (CC1), R6.1
unnamed: K20.B5 (CC2), R7.1
unnamed: Q2.1 (B), R12.2
unnamed: Q3.1 (B), R13.2
unnamed: R10.1, U3.5 (PROG)
RTS: Q2.2 (E), R13.1, U2.14 (RTS#)
RXD: R9.1; also elsewhere on the board
TXD: R8.1; also elsewhere on the board
VBAT: C7.2, PAD1.1, Q1.3 (D), U3.3 (VBAT)
VIN: C8.2, C9.2, C10.2, D2.2 (K), PAD5.1, Q1.2 (S), U4.4 (EN), U4.6 (IN)
VUSB: C5.2, D2.1 (A), F1.1, Q1.1 (G), R5.1, R11.1, U2.16 (VCC), U3.4 (VDD)

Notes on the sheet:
POWER PORTS
POWER PADS
BATTERY CHARGER
VOLTAGE REGULATOR
AUTO-RESET CIRCUIT
AUTO SOURCE SELSCTION
USB-C CONNECTOR
USB-UART CONVERTER

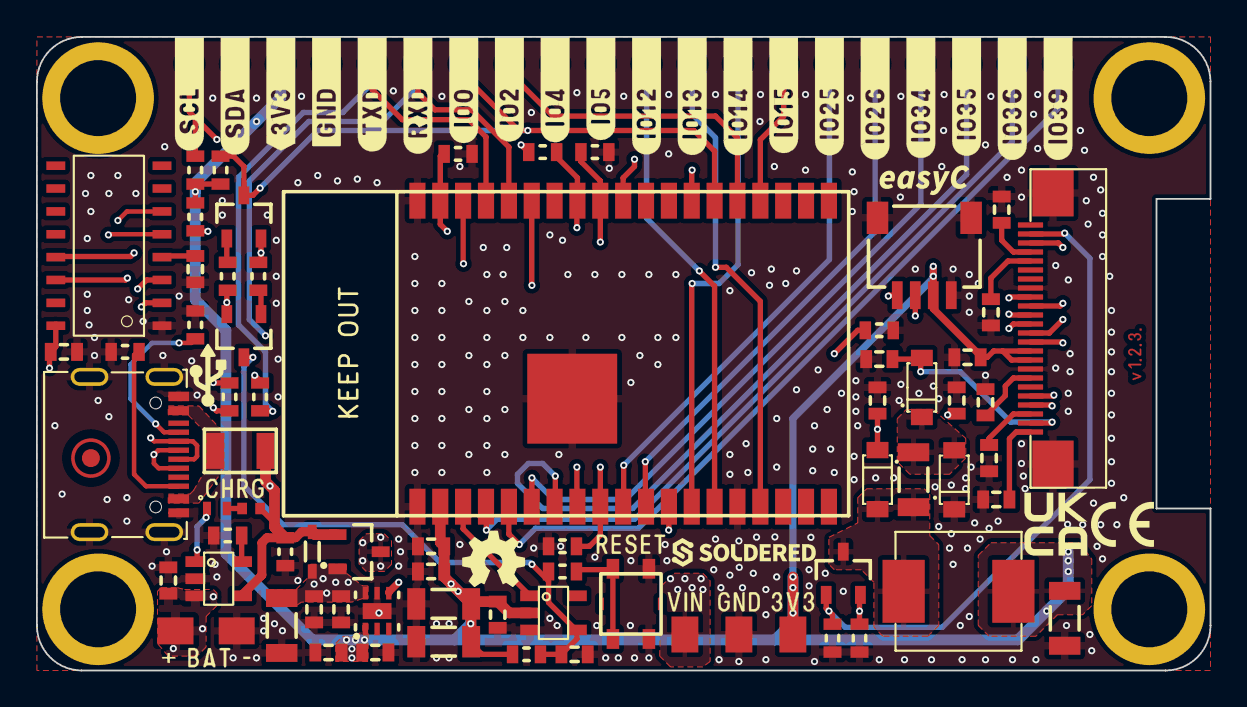
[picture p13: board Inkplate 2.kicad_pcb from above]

Board: 4 copper layers, 65.2 x 35.2 mm, 98 parts (1 on the bottom side), 59 nets.
